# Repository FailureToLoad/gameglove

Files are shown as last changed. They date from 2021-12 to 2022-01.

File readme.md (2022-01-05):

# Game Glove

Having grown tired of trying different keyboard layouts that all always felt slightly off, I set out to design a gaming peripheral that felt right.

## Objectives

### 1. Small footprint

This is a perpipheral that will sit along side my normal keyboard so it should be half the size of a 60% at most.

### 2. Should be able to press the 2 and 3 keys with middle finger

I can't shake this very specific muscle memory, so may as well design around it.

### 3. Row aligned, column staggered, WASD oriented

I've never been able to hit keys like Z, X, and C reliably. My brain refuses to memorize the meat signals to reach down, then laterally. That led me to at least remove the lateral movement by going for something ortholinear-ish.

Pure ortholinear was uncomfortable for me, but column staggered ortho made a lot of sense. The problem is that most column staggered layouts base the spacing off of home-row hand positioning. This is for gaming, so the spacing should be oriented around WASD positioning.

### 4. Modifier keys must be larger than 1u

From trying pure ortholinear, my hands felt fairly cramped with 1u modifier keys.

## V1

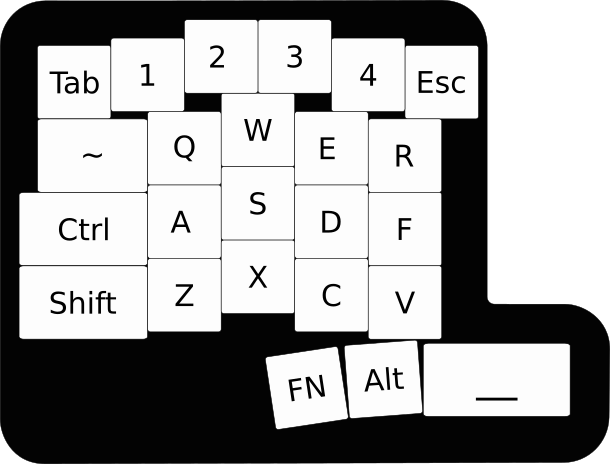
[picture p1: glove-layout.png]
v1


After a fair amount of iteration and prototyping, I've landed on the following.

### 4x5 + 4 Layout

I liked the look of 6 keys on row 1 and row 5 felt just right at 3 keys.

### Row staggered first and last row

Row staggering the first row got me my 2/3 key situation I wanted. The last row was positioned based off of where my thumb comfortably sits.

I cannot stress how much time I spent measuring the thumb positioning. It is maddening how many ways there are to do it wrong.

### WASD oriented

I shifted the spacing so that W defines the "peak" of the column staggering.

### Modifier key sizing

I changed the shift to be 1.75u to avoid non-standard sizing issues with keycap sets and then right-justified the modifiers to conform to the row-aligned, column-staggered requirement.

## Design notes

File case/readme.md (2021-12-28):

# Case Properties

* All SVG editing done with inkscape.
* All DXF editing done with Qcad.

## Keycap Angles

Refer to gameglove.h in the qmk folder for numbering. These are the keys in the last row, from left to right.

| Key | Degrees |
|---|---|
| 42 | -8.6 |
| 43 | -4.3 |
| 44 | 90 |

## Case Materials

|  Layer | Material | Thickness |
|---:|---|---|
| Switch | ABS | 4.7mm |
| Mid | Acrylic  | 4.5mm |
| Bottom | Acrylic  | 4.5mm |

There was no logic behind using ABS for the plate, I was just browsing materials on [SendCutSend](https://sendcutsend.com/) and decided to try it. When using SendCutSend make sure to follow their guidelines on [CNC Routing](https://sendcutsend.com/cnc-guidelines/).

I know the space key looks... funky. The cutout takes into account the thickness of the switch place.

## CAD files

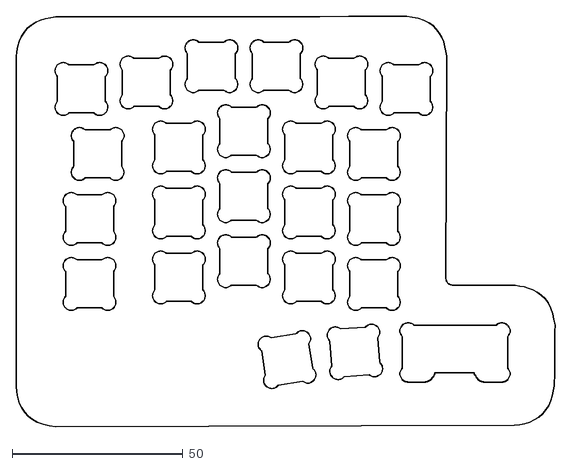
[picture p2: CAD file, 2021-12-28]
case/sendcutsend/glove-switch-scs.dxf
158.0 x 120.3

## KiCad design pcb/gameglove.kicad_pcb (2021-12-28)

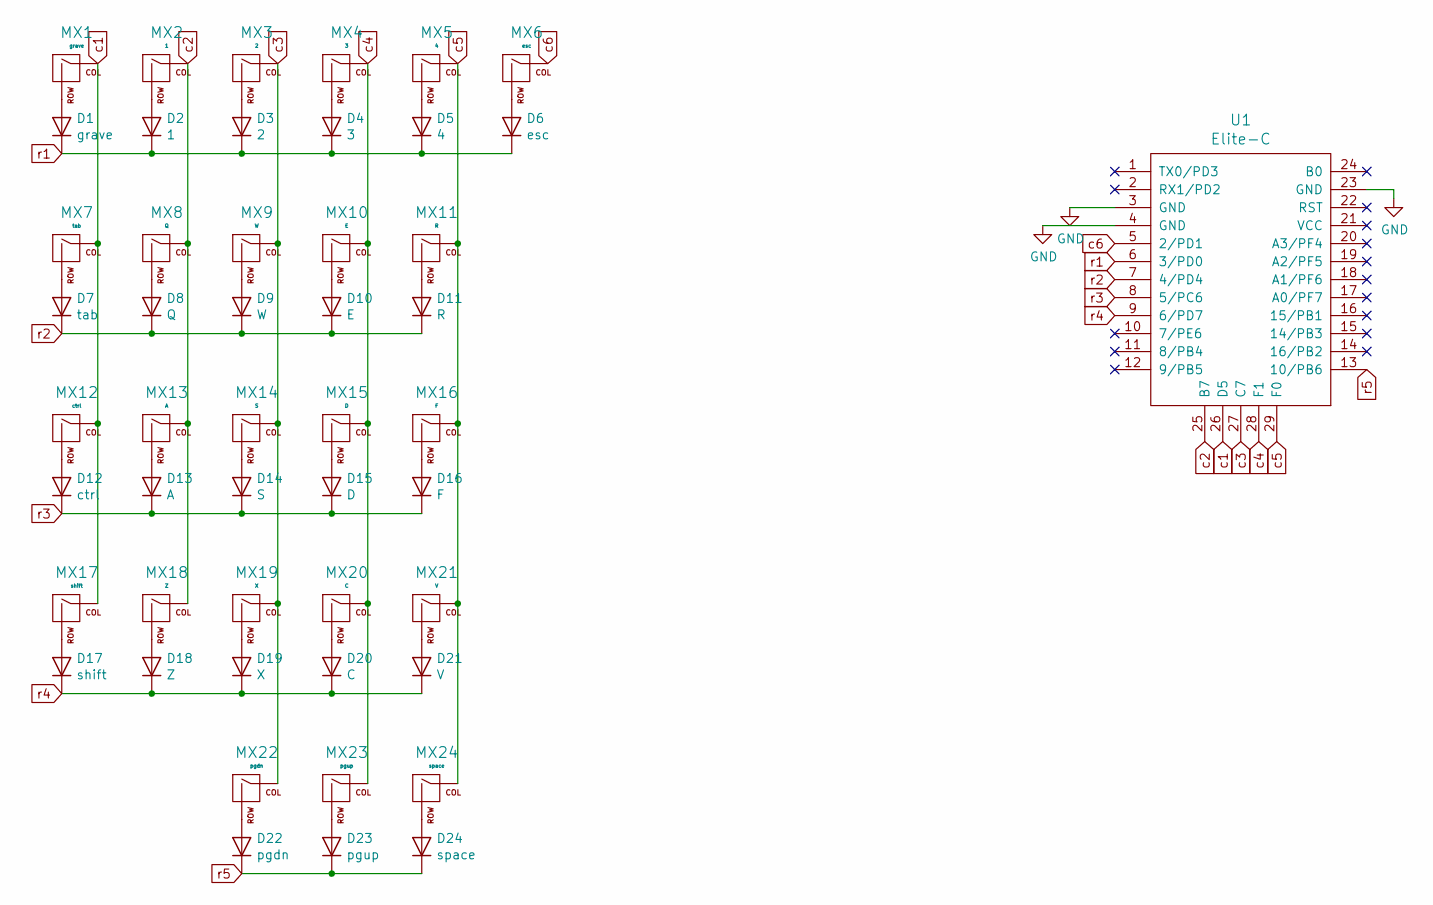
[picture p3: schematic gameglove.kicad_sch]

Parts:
D1: grave; D_axial
D2: 1; D_axial
D3: 2; D_axial
D4: 3; D_axial
D5: 4; D_axial
D6: esc; D_axial
D7: tab; D_axial
D8: Q; D_axial
D9: W; D_axial
D10: E; D_axial
D11: R; D_axial
D12: ctrl; D_axial
D13: A; D_axial
D14: S; D_axial
D15: D; D_axial
D16: F; D_axial
D17: shift; D_axial
D18: Z; D_axial
D19: X; D_axial
D20: C; D_axial
D21: V; D_axial
D22: pgdn; D_axial
D23: pgup; D_axial
D24: space; D_axial
MX1: grave; MXOnly-1U-NoLED
MX2: 1; MXOnly-1U-NoLED
MX3: 2; MXOnly-1U-NoLED
MX4: 3; MXOnly-1U-NoLED
MX5: 4; MXOnly-1U-NoLED
MX6: esc; MXOnly-1U-NoLED
MX7: tab; MXOnly-1.5U-NoLED
MX8: Q; MXOnly-1U-NoLED
MX9: W; MXOnly-1U-NoLED
MX10: E; MXOnly-1U-NoLED
MX11: R; MXOnly-1U-NoLED
MX12: ctrl; MXOnly-1.75U-NoLED
MX13: A; MXOnly-1U-NoLED
MX14: S; MXOnly-1U-NoLED
MX15: D; MXOnly-1U-NoLED
MX16: F; MXOnly-1U-NoLED
MX17: shift; MXOnly-1.75U-NoLED
MX18: Z; MXOnly-1U-NoLED
MX19: X; MXOnly-1U-NoLED
MX20: C; MXOnly-1U-NoLED
MX21: V; MXOnly-1U-NoLED
MX22: pgdn; MXOnly-1U-NoLED
MX23: pgup; MXOnly-1U-NoLED
MX24: space; MXOnly-2U-NoLED
U1: Elite-C; Elite-C-castellated-29pin-holes

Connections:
GND: U1.3 (GND), U1.4 (GND), U1.23 (GND)
unnamed: D1.2 (A), MX1.2 (ROW)
unnamed: D2.2 (A), MX2.2 (ROW)
unnamed: D3.2 (A), MX3.2 (ROW)
unnamed: D4.2 (A), MX4.2 (ROW)
unnamed: D5.2 (A), MX5.2 (ROW)
unnamed: D6.2 (A), MX6.2 (ROW)
unnamed: D7.2 (A), MX7.2 (ROW)
unnamed: D8.2 (A), MX8.2 (ROW)
unnamed: D9.2 (A), MX9.2 (ROW)
unnamed: D10.2 (A), MX10.2 (ROW)
unnamed: D11.2 (A), MX11.2 (ROW)
unnamed: D12.2 (A), MX12.2 (ROW)
unnamed: D13.2 (A), MX13.2 (ROW)
unnamed: D14.2 (A), MX14.2 (ROW)
unnamed: D15.2 (A), MX15.2 (ROW)
unnamed: D16.2 (A), MX16.2 (ROW)
unnamed: D17.2 (A), MX17.2 (ROW)
unnamed: D18.2 (A), MX18.2 (ROW)
unnamed: D19.2 (A), MX19.2 (ROW)
unnamed: D20.2 (A), MX20.2 (ROW)
unnamed: D21.2 (A), MX21.2 (ROW)
unnamed: D22.2 (A), MX22.2 (ROW)
unnamed: D23.2 (A), MX23.2 (ROW)
unnamed: D24.2 (A), MX24.2 (ROW)
c1: MX1.1 (COL), MX7.1 (COL), MX12.1 (COL), MX17.1 (COL), U1.26 (D5)
c2: MX2.1 (COL), MX8.1 (COL), MX13.1 (COL), MX18.1 (COL), U1.25 (B7)
c3: MX3.1 (COL), MX9.1 (COL), MX14.1 (COL), MX19.1 (COL), MX22.1 (COL), U1.27 (C7)
c4: MX4.1 (COL), MX10.1 (COL), MX15.1 (COL), MX20.1 (COL), MX23.1 (COL), U1.28 (F1)
c5: MX5.1 (COL), MX11.1 (COL), MX16.1 (COL), MX21.1 (COL), MX24.1 (COL), U1.29 (F0)
c6: MX6.1 (COL), U1.5 (2/PD1)
r1: D1.1 (K), D2.1 (K), D3.1 (K), D4.1 (K), D5.1 (K), D6.1 (K), U1.6 (3/PD0)
r2: D7.1 (K), D8.1 (K), D9.1 (K), D10.1 (K), D11.1 (K), U1.7 (4/PD4)
r3: D12.1 (K), D13.1 (K), D14.1 (K), D15.1 (K), D16.1 (K), U1.8 (5/PC6)
r4: D17.1 (K), D18.1 (K), D19.1 (K), D20.1 (K), D21.1 (K), U1.9 (6/PD7)
r5: D22.1 (K), D23.1 (K), D24.1 (K), U1.13 (10/PB6)

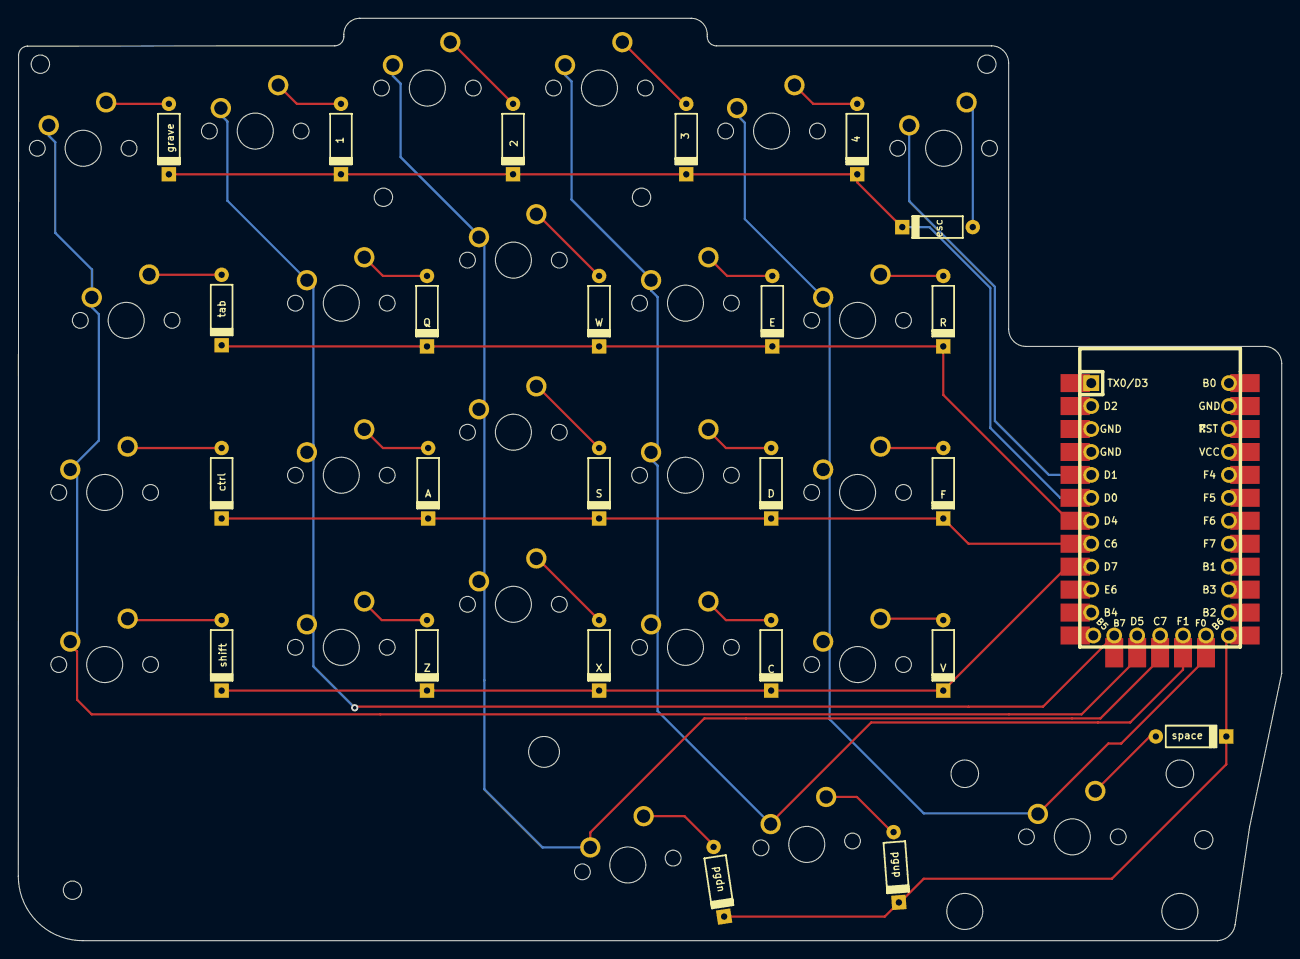
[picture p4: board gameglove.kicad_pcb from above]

Board: 2 copper layers, 139.9 x 102.1 mm, 49 parts (0 on the bottom side), 36 nets.

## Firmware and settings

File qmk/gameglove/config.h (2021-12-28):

#ifndef CONFIG_H
#define CONFIG_H

#include "config_common.h"

/* USB Device descriptor parameter */
#define VENDOR_ID       0xFEED
#define PRODUCT_ID      0x6060
#define DEVICE_VER      0x0001
#define MANUFACTURER    qmkbuilder
#define PRODUCT         gameglove
#define DESCRIPTION     gameglove

/* key matrix size */
#define MATRIX_ROWS 5
#define MATRIX_COLS 6

/* key matrix pins */
#define MATRIX_ROW_PINS { D0, D4, C6, D7, B6 }
#define MATRIX_COL_PINS { D5, B7, C7, F1, F0, D1 }
#define UNUSED_PINS

/* COL2ROW or ROW2COL */
#define DIODE_DIRECTION COL2ROW

/* Set 0 if debouncing isn't needed */
#define DEBOUNCING_DELAY 5


/* prevent stuck modifiers */
#define PREVENT_STUCK_MODIFIERS

#endif
